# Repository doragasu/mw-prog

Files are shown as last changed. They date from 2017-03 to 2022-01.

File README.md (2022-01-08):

# WARNING: THIS PROJECT HAS MOVED

You can find the most recent version at the [mw-prog GitLab project page](https://gitlab.com/doragasu/mw-prog). This repository will be kept as is, and will not be updated anymore.

# mw-prog
MegaWiFi Programmer

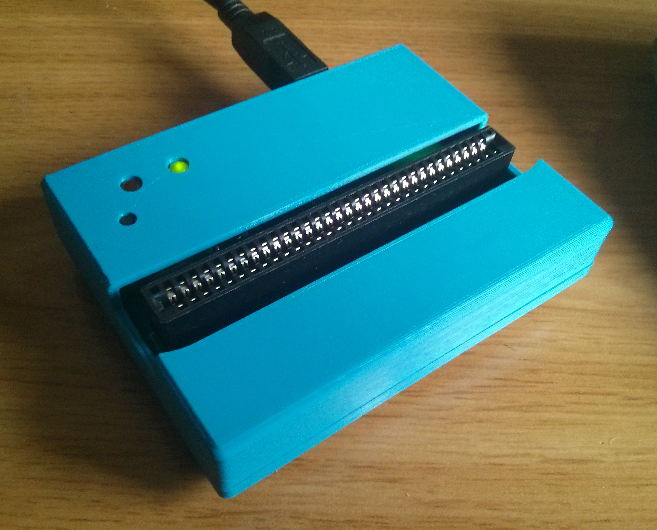
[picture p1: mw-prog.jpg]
mw-prog


This programmer is for the MegaWiFi project. It can write SEGA Genesis/Megadrive ROM files to MegaWiFi cartridges (up to 32 Mbit). It can also upload firmware blobs to the WiFi module inside MegaWiFi cartridges. To do so, you will need:

- Programmer bootloader: https://github.com/doragasu/mw-mdma-bl
- Programmer firmware: https://github.com/doragasu/mw-mdma-fw
- Programmer command-line interface: https://github.com/doragasu/mw-mdma-cli

And of course a both a MegaWiFi programmer and the target MegaWiFi cartridge.

This project was initially created for 1985alternativo, but to this day, no brave soul has dared to make an online game using this cart. Are you brave enough to try?

## License
mw-prog is licensed under the [CERN OHL 1.2](http://www.ohwr.org/licenses/cern-ohl/v1.2) license. You are free to study, distribute and make modifications to the Documentation, under the aforementioned license terms. You are also free to make cartridges derived from the Documentation for non-commercial purposes. If you want to make a commercial Product using this Documentation, please contact me to obtain a licence.

## About CAD files
Electronic CAD design files are for KiCAD Open Source electronics design suite. Please install latest version along with KiCAD libraries to open the project. When opening schematic, KiCAD will most likely complain about missing library "doragasu". Despite this warning, the schematic should load nicely (using the cached libraries). To avoid this message, install [the missing library](https://github.com/doragasu/doragasu-kicad-lib) and make sure to configure it in the schematic editor.

The files under `gerber` directory are for PCB fabrication. Send them to your favorite PCB fab house.

Files under `enclosure` directory are for the design and fabrication of the PCB enclosure. You can 3D-print the OBJ files to have a not specially pretty but functional enclosure for the programmer. If you want to edit the design files, you will need FreeCAD.

Enjoy!

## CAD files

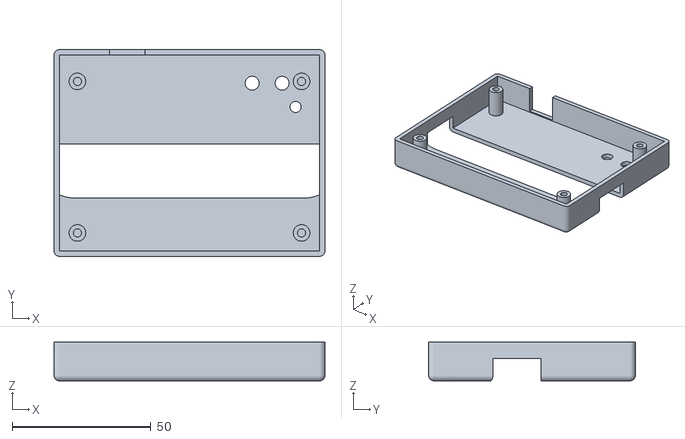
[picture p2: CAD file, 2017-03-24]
enclosure/mega-prog-top.obj
97.7 x 74.5 x 14.0

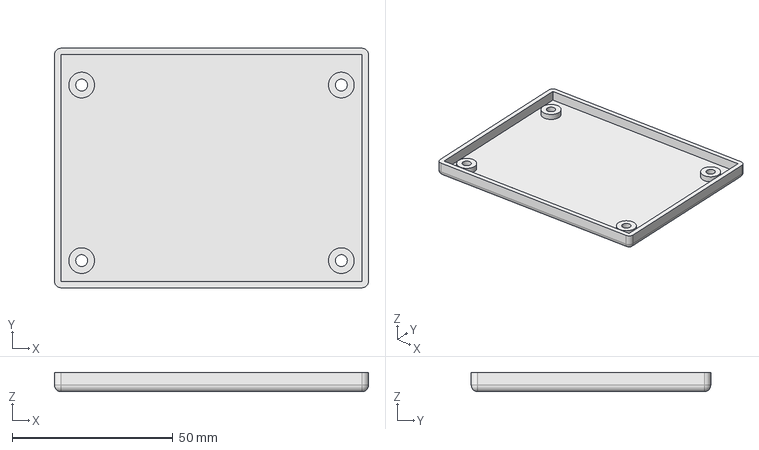
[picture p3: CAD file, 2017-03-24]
enclosure/mega-prog-bot.fcstd
97.7 x 74.5 x 6.00 mm

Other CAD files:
enclosure/mega-prog-bot.obj

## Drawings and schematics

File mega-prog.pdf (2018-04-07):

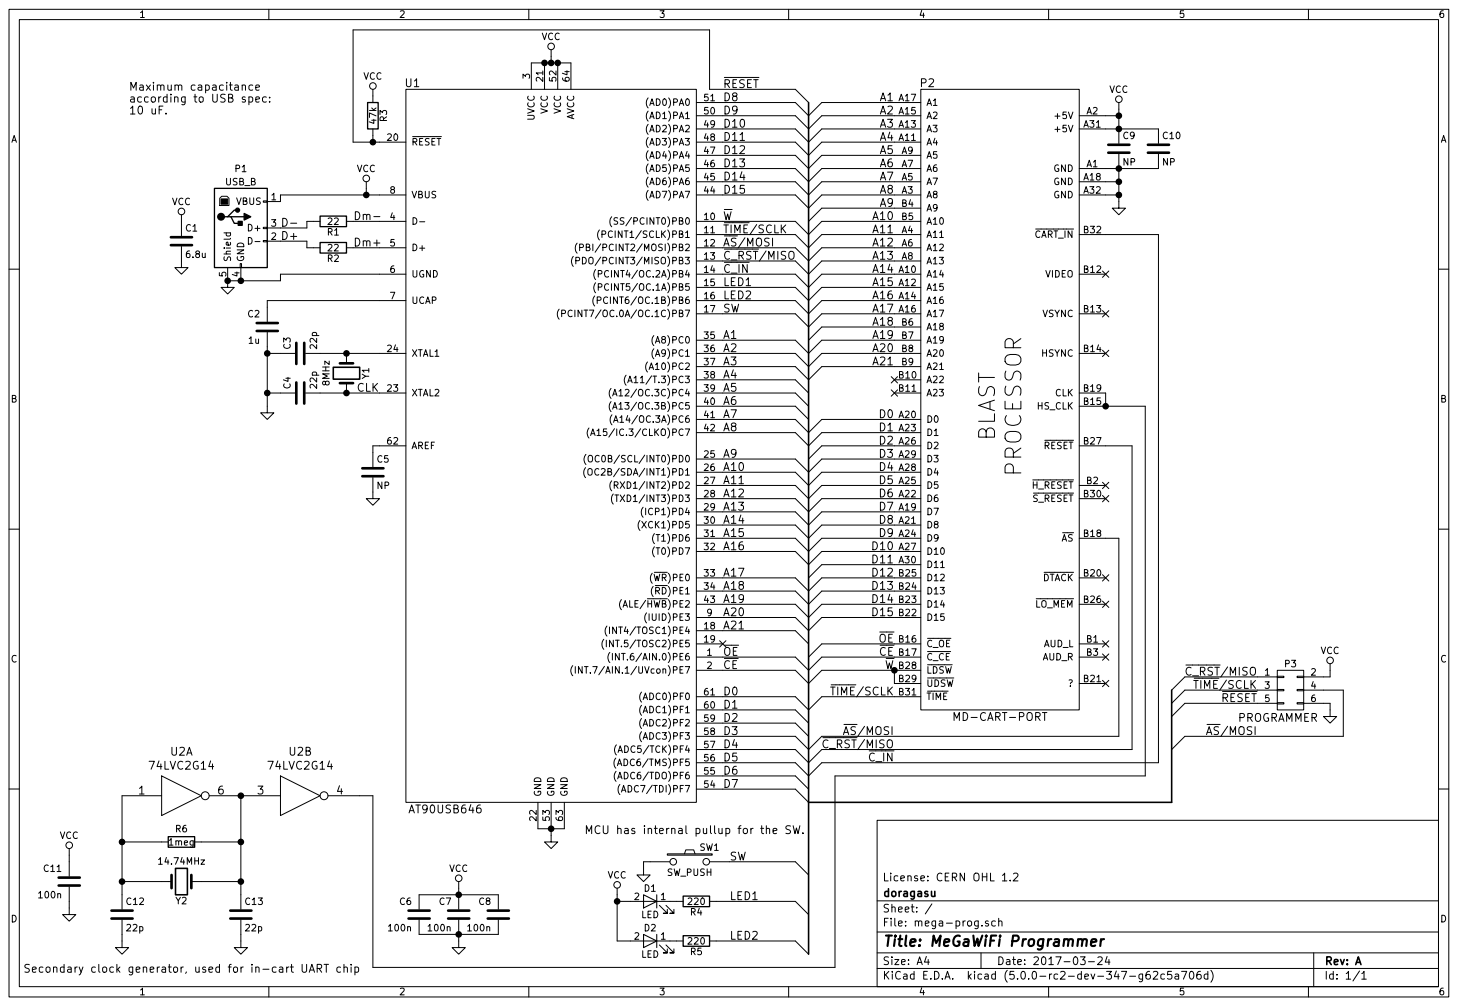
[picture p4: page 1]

VCC MCU has internal pullup for the SW.

License: CERN OHL 1.2
File: mega-prog.sch Sheet: / doragasu

Id: 1/1 Title: MeGaWiFi Programmer

Secondary clock generator, used for in-cart UART chip

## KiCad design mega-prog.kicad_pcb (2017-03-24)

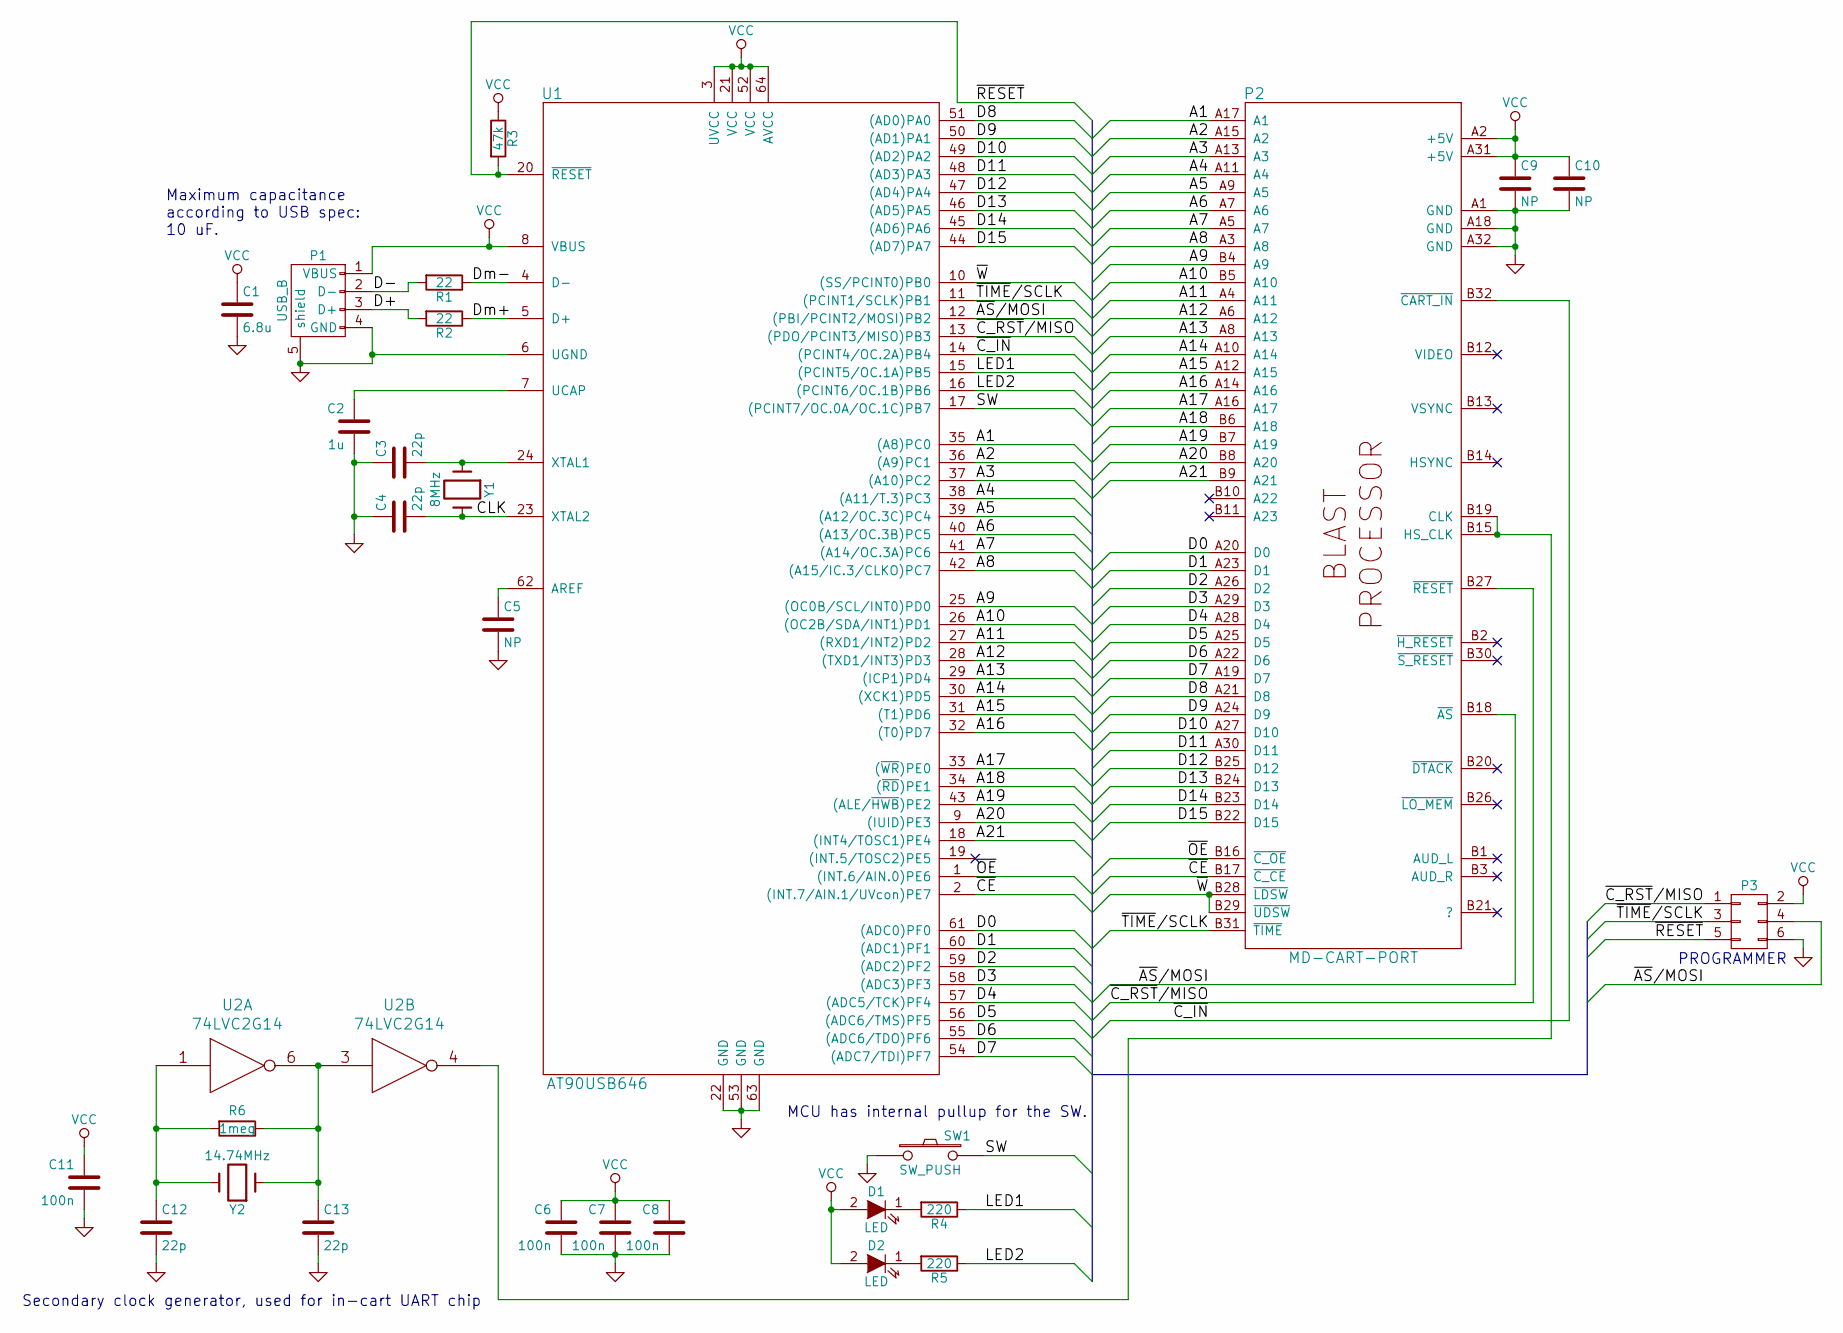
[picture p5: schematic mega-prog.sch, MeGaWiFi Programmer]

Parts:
C1: 6.8u; Capacitor5x11RM2.5
C2: 1u; C_0805
C3, C4, C12, C13: 22p; C_0805
C5, C9, C10: NP; C_0805
C6, C7, C8, C11: 100n; C_0805
D1, D2: LED; LED-5MM
P1: USB_B
P2: MD-CART-PORT; GEN_CART_PORT
P3: CONN_02X03; Pin_Header_Straight_2x03
R1, R2: 22; R_0805
R3: 47k; R_0805
R4, R5: 220; R_0805
R6: 1meg; R_0805
SW1: SW_PUSH; SW_PUSH_SMALL
U1: AT90USB646; LQFP-64_14x14mm_Pitch0.8mm
U2: 74LVC2G14; SOT23-6
Y1: 8MHz; Crystal_HC49-U_Vertical
Y2: 14.74MHz; Crystal_HC49-U_Vertical

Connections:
/A1: P2.A17 (A1), U1.35 ((A8)PC0)
/A2: P2.A15 (A2), U1.36 ((A9)PC1)
/A3: P2.A13 (A3), U1.37 ((A10)PC2)
/A4: P2.A11 (A4), U1.38 ((A11/T.3)PC3)
/A5: P2.A9 (A5), U1.39 ((A12/OC.3C)PC4)
/A6: P2.A7 (A6), U1.40 ((A13/OC.3B)PC5)
/A7: P2.A5 (A7), U1.41 ((A14/OC.3A)PC6)
/A8: P2.A3 (A8), U1.42 ((A15/IC.3/CLKO)PC7)
/A9: P2.B4 (A9), U1.25 ((OC0B/SCL/INT0)PD0)
/A10: P2.B5 (A10), U1.26 ((OC2B/SDA/INT1)PD1)
/A11: P2.A4 (A11), U1.27 ((RXD1/INT2)PD2)
/A12: P2.A6 (A12), U1.28 ((TXD1/INT3)PD3)
/A13: P2.A8 (A13), U1.29 ((ICP1)PD4)
/A14: P2.A10 (A14), U1.30 ((XCK1)PD5)
/A15: P2.A12 (A15), U1.31 ((T1)PD6)
/A16: P2.A14 (A16), U1.32 ((T0)PD7)
/A17: P2.A16 (A17), U1.33 ((~WR~)PE0)
/A18: P2.B6 (A18), U1.34 ((~RD~)PE1)
/A19: P2.B7 (A19), U1.43 ((ALE/~HWB~)PE2)
/A20: P2.B8 (A20), U1.9 ((IUID)PE3)
/A21: P2.B9 (A21), U1.18 ((INT4/TOSC1)PE4)
/CLK: C4.2, U1.23 (XTAL2), Y1.2
/D0: P2.A20 (D0), U1.61 ((ADC0)PF0)
/D1: P2.A23 (D1), U1.60 ((ADC1)PF1)
/D2: P2.A26 (D2), U1.59 ((ADC2)PF2)
/D3: P2.A29 (D3), U1.58 ((ADC3)PF3)
/D4: P2.A28 (D4), U1.57 ((ADC5/TCK)PF4)
/D5: P2.A25 (D5), U1.56 ((ADC6/TMS)PF5)
/D6: P2.A22 (D6), U1.55 ((ADC6/TDO)PF6)
/D7: P2.A19 (D7), U1.54 ((ADC7/TDI)PF7)
/D8: P2.A21 (D8), U1.51 ((AD0)PA0)
/D9: P2.A24 (D9), U1.50 ((AD1)PA1)
/D10: P2.A27 (D10), U1.49 ((AD2)PA2)
/D11: P2.A30 (D11), U1.48 ((AD3)PA3)
/D12: P2.B25 (D12), U1.47 ((AD4)PA4)
/D13: P2.B24 (D13), U1.46 ((AD5)PA5)
/D14: P2.B23 (D14), U1.45 ((AD6)PA6)
/D15: P2.B22 (D15), U1.44 ((AD7)PA7)
/D+: P1.3 (D+), R2.2
/D-: P1.2 (D-), R1.2
/Dm+: R2.1, U1.5 (D+)
/Dm-: R1.1, U1.4 (D-)
/LED1: R4.1, U1.15 ((PCINT5/OC.1A)PB5)
/LED2: R5.1, U1.16 ((PCINT6/OC.1B)PB6)
/SW: SW1.2, U1.17 ((PCINT7/OC.0A/OC.1C)PB7)
/~AS~/MOSI: P2.B18 (~AS), P3.4, U1.12 ((PBI/PCINT2/MOSI)PB2)
/~CE: P2.B17 (~C_CE), U1.2 ((INT.7/AIN.1/UVcon)PE7)
/~C_IN: P2.B32 (~CART_IN), U1.14 ((PCINT4/OC.2A)PB4)
/~C_RST~/MISO: P2.B27 (~RESET), P3.1, U1.13 ((PDO/PCINT3/MISO)PB3)
/~OE: P2.B16 (~C_OE), U1.1 ((INT.6/AIN.0)PE6)
/~RESET: P3.5, R3.2, U1.20 (~RESET)
/~TIME~/SCLK: P2.B31 (~TIME), P3.3, U1.11 ((PCINT1/SCLK)PB1)
/~W: P2.B28 (~LDSW), P2.B29 (~UDSW), U1.10 ((SS/PCINT0)PB0)
GND: C1.2, C2.2, C3.1, C4.1, C5.2, C6.2, C7.2, C8.2, C9.2, C10.2, C11.2, C12.2, C13.2, P1.4 (GND), P1.5 (shield), P2.A1 (GND), P2.A18 (GND), P2.A32 (GND), P3.6, SW1.1, U1.6 (UGND), U1.22 (GND), U1.53 (GND), U1.63 (GND), U2.2 (GND)
unnamed: C2.1, U1.7 (UCAP)
unnamed: C3.2, U1.24 (XTAL1), Y1.1
unnamed: C5.1, U1.62 (AREF)
unnamed: C12.1, R6.2, U2.1, Y2.2
unnamed: C13.1, R6.1, U2.3, U2.6, Y2.1
unnamed: D1.1 (K), R4.2
unnamed: D2.1 (K), R5.2
unnamed: P2.B15 (HS_CLK), P2.B19 (CLK), U2.4
VCC: C1.1, C6.1, C7.1, C8.1, C9.1, C10.1, C11.1, D1.2 (A), D2.2 (A), P1.1 (VBUS), P2.A2 (+5V), P2.A31 (+5V), P3.2, R3.1, U1.3 (UVCC), U1.8 (VBUS), U1.21 (VCC), U1.52 (VCC), U1.64 (AVCC), U2.5 (VCC)

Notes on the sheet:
MCU has internal pullup for the SW.
Maximum capacitance according to USB spec: 10 uF.
PROGRAMMER
Secondary clock generator, used for in-cart UART chip

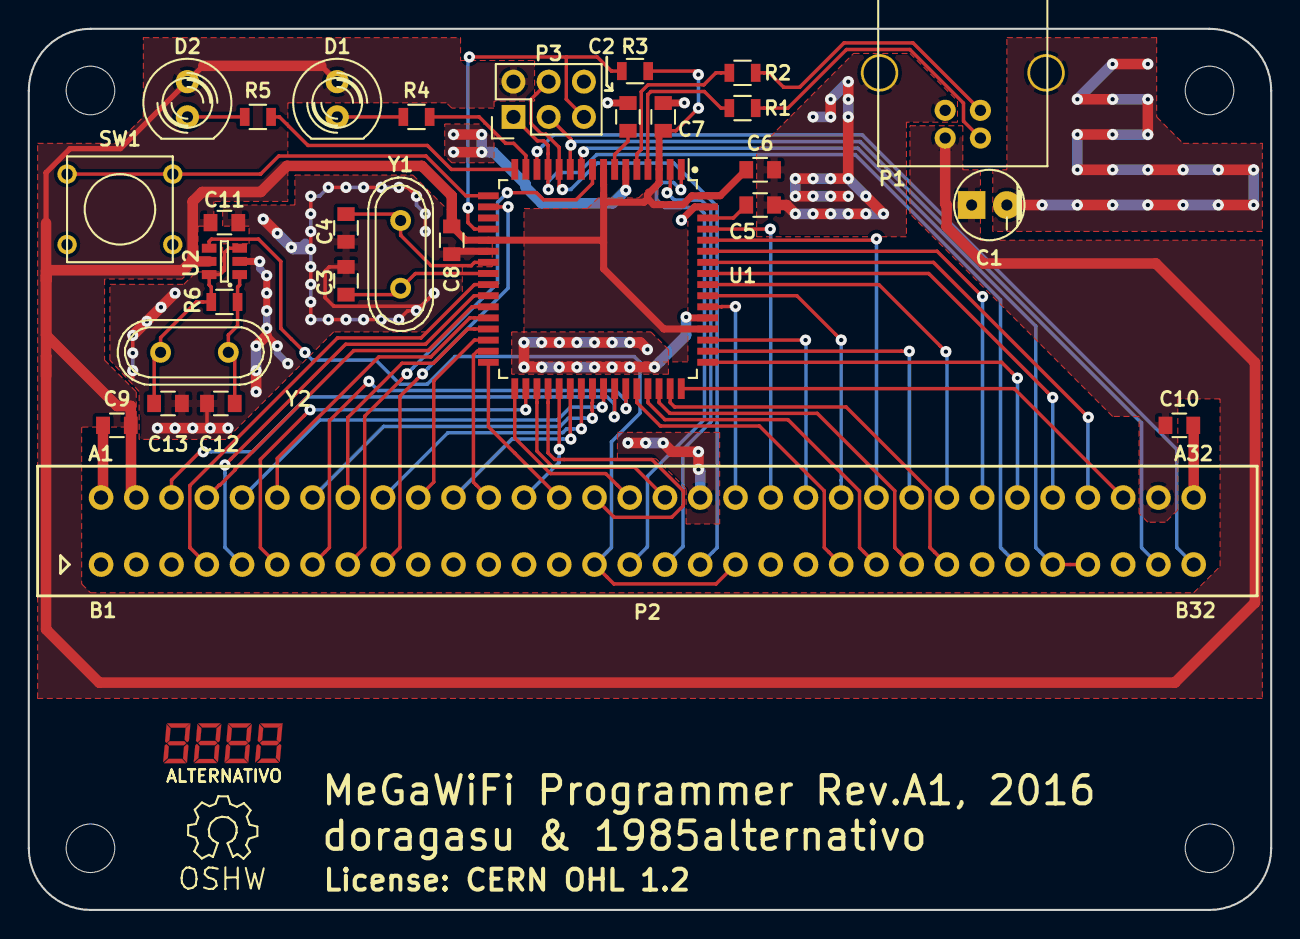
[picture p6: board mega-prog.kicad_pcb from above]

Board: 2 copper layers, 89.5 x 63.5 mm, 34 parts (0 on the bottom side), 63 nets.

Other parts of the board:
MountingHole_3-5mm, MountingHole_3-5mm#2, MountingHole_3-5mm#3, MountingHole_3-5mm#4: VAL**; MountingHole_3-5mm
Symbol_OSHW-Logo_SilkScreen: VAL**; Symbol_OSHW-Logo_SilkScreen

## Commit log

2017-03-24 Added design files.
    [mega-prog-B.Cu.gbr, mega-prog-B.Mask.gbr, mega-prog-Edge.Cuts.gbr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]
2017-09-24 BOM changes.
    [mega-prog.sch]
2018-04-07 Updated to latest KiCad and libraries version.
    [mega-prog.sch]

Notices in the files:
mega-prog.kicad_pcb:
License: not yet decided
